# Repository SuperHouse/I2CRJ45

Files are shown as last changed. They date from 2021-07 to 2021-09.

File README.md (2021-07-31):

I2C to RJ45 Breakouts for Light Switch Controller
=================================================

Copyright 2019-2021 SuperHouse Automation Pty Ltd  www.superhouse.tv

These I2C to RJ45 breakouts are one component of the SuperHouse home
automation light switch controller project. They allow light switches
to be connected to a controller such as an Arduino, Raspberry Pi,
or ESP8266/ESP32 board.

The RJ45 sockets on the breakout are connected to I/O channels via
I2C addressable I/O buffers. Each RJ45 socket provides connections for
GND, 12V, and 4 signal lines.

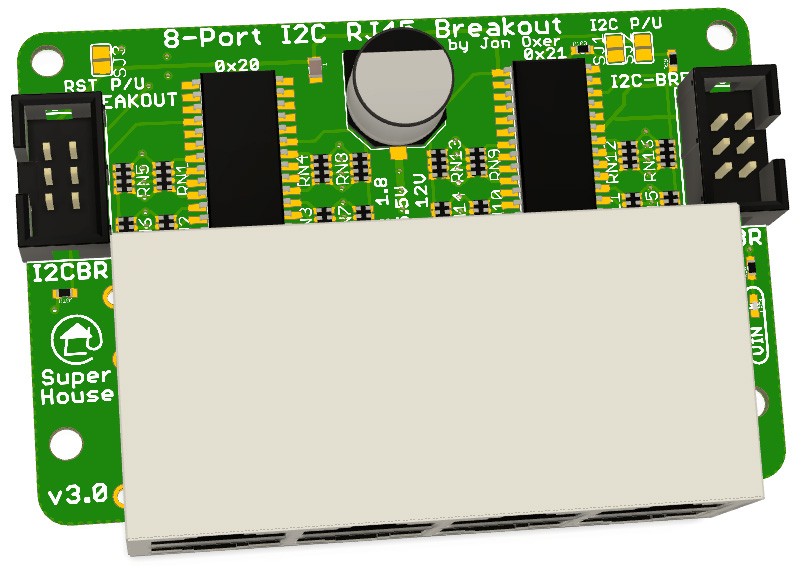
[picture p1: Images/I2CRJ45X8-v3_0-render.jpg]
8-port I2C RJ45 Breakout PCB


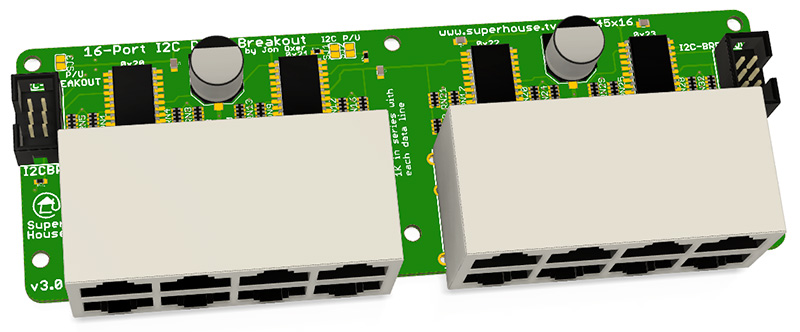
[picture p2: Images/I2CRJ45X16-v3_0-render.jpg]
16-port I2C RJ45 Breakout PCB


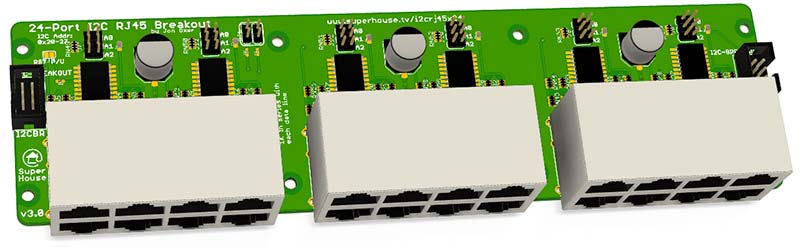
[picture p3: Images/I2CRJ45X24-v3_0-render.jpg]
24-port I2C RJ45 Breakout PCB


Features:

 * RJ45 sockets for connection to light switches over Cat-5
 * I2C interface with interrupt output

More information on the Light Switch Controller project:

  http://www.superhouse.tv/lsc

The LSC also has its own GitHub repo which includes example firmware:

  https://github.com/SuperHouse/LSC

Purchase these breakouts pre-assembled:

  http://www.superhouse.tv/i2crj45

INSTALLATION
------------
The design is saved as an EAGLE project. EAGLE PCB design software is
available from www.cadsoftusa.com free for non-commercial use. To use
this project download it and place the directory containing these files
into the "eagle" directory on your computer. Then open EAGLE and
navigate to the project.

CREDITS
-------
Designed by Jonathan Oxer jon@oxer.com.au

Mechanical drawings by Aaron Knox

DISTRIBUTION
------------
The specific terms of distribution of this project are governed by the
license referenced below.

LICENSE
-------
Licensed under the TAPR Open Hardware License (www.tapr.org/OHL).
The "license" folder within this repository also contains a copy of
this license in plain text format.

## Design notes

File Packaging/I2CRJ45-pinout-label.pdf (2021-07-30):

# I2C Breakout to RJ45

# www.superhouse.tv/i2crj45

A2 A2 A2 A2 A2 A2
A1 A1 A1 A1 A1 A1
A0 A0 A0 A0 A0 A0

A2 A2 A2 A2 A2 A2
A1 A1 A1 A1 A1 A1
A0 A0 A0 A0 A0 A0

# www.superhouse.tv

# I2C Breakout to RJ45

# www.superhouse.tv/i2crj45

A2 A2 A2 A2 A2 A2
A1 A1 A1 A1 A1 A1
A0 A0 A0 A0 A0 A0

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

# www.superhouse.tv

# I2C Breakout to RJ45

# www.superhouse.tv/i2crj45

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

# www.superhouse.tv

# I2C Breakout to RJ45

# www.superhouse.tv/i2crj45

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

# www.superhouse.tv

# I2C Breakout to RJ45

# www.superhouse.tv/i2crj45

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

# www.superhouse.tv

# I2C Breakout to RJ45

# www.superhouse.tv/i2crj45

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

# www.superhouse.tv

# I2C Breakout to RJ45

# www.superhouse.tv/i2crj45

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

# www.superhouse.tv

# I2C Breakout to RJ45

# www.superhouse.tv/i2crj45

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

# www.superhouse.tv

# I2C Breakout to RJ45

# www.superhouse.tv/i2crj45

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

# www.superhouse.tv

# I2C Breakout to RJ45

# www.superhouse.tv/i2crj45

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

# www.superhouse.tv

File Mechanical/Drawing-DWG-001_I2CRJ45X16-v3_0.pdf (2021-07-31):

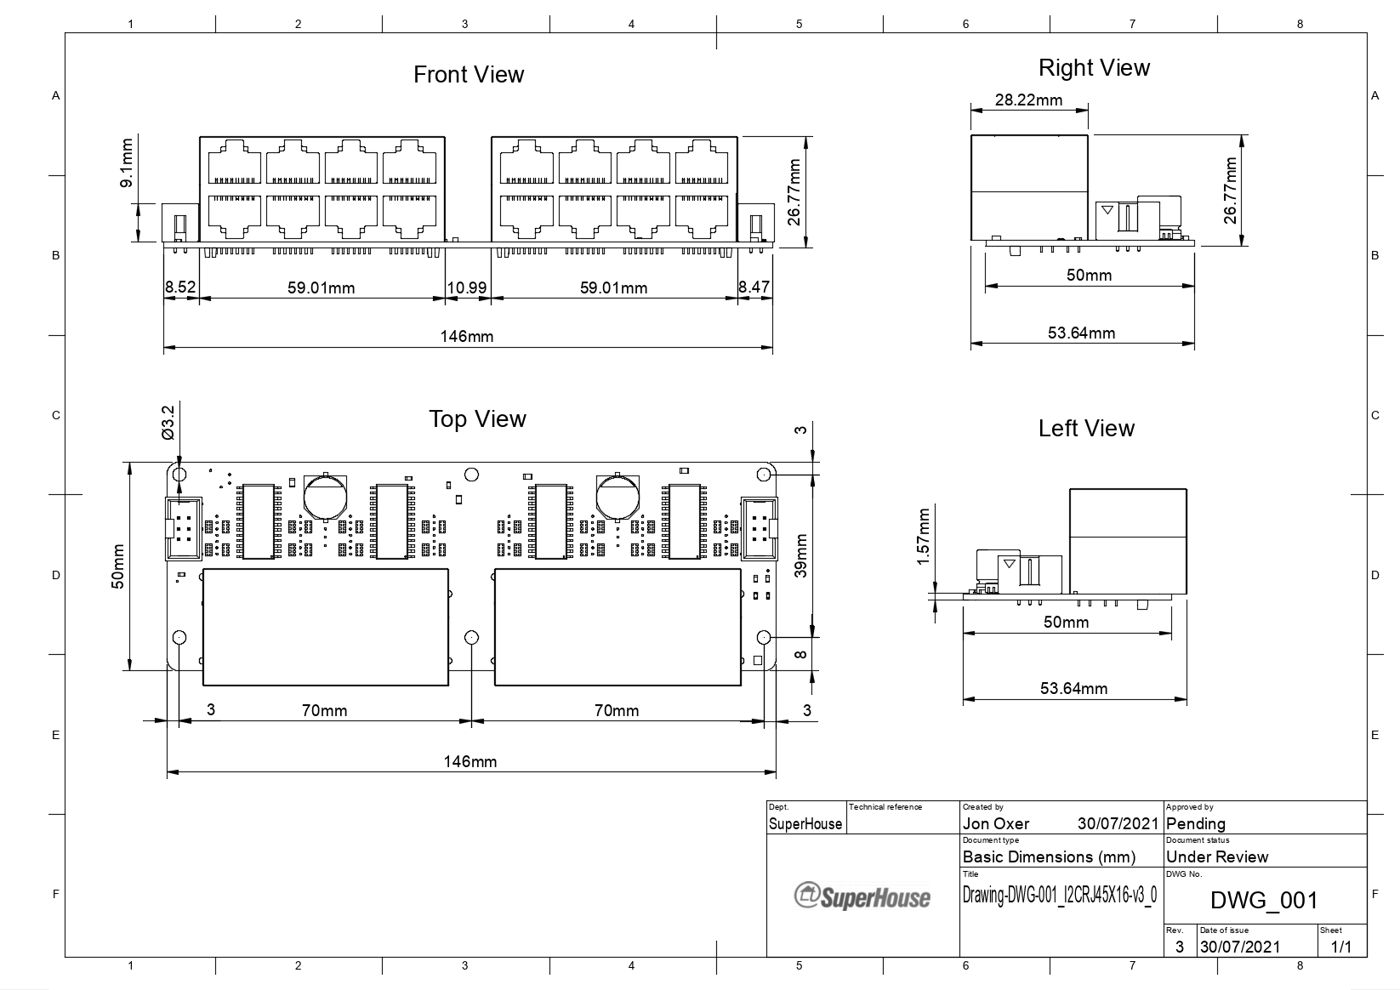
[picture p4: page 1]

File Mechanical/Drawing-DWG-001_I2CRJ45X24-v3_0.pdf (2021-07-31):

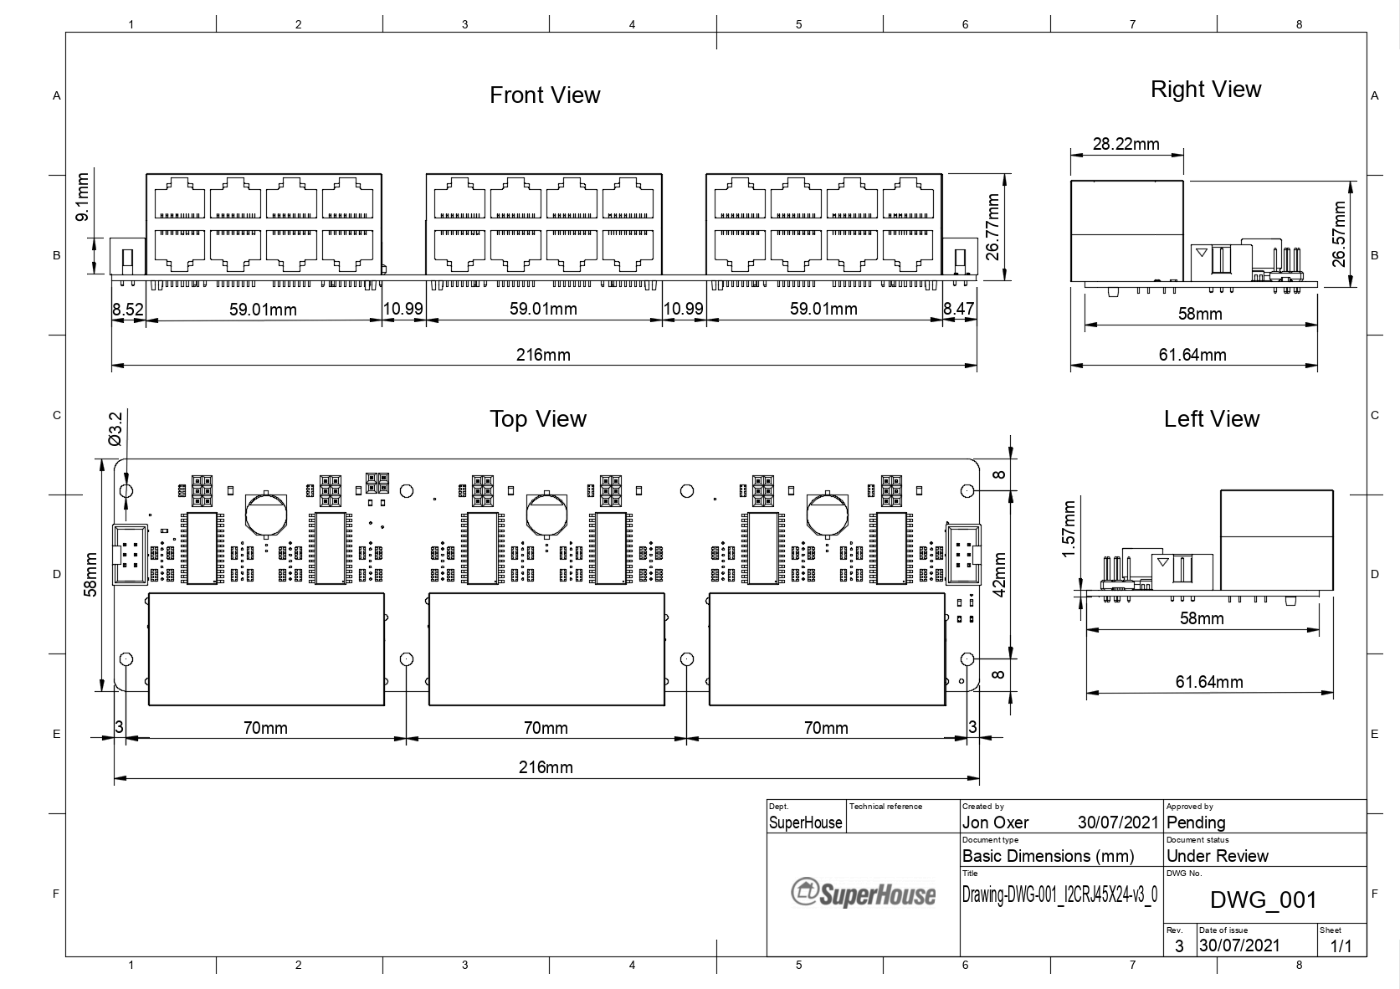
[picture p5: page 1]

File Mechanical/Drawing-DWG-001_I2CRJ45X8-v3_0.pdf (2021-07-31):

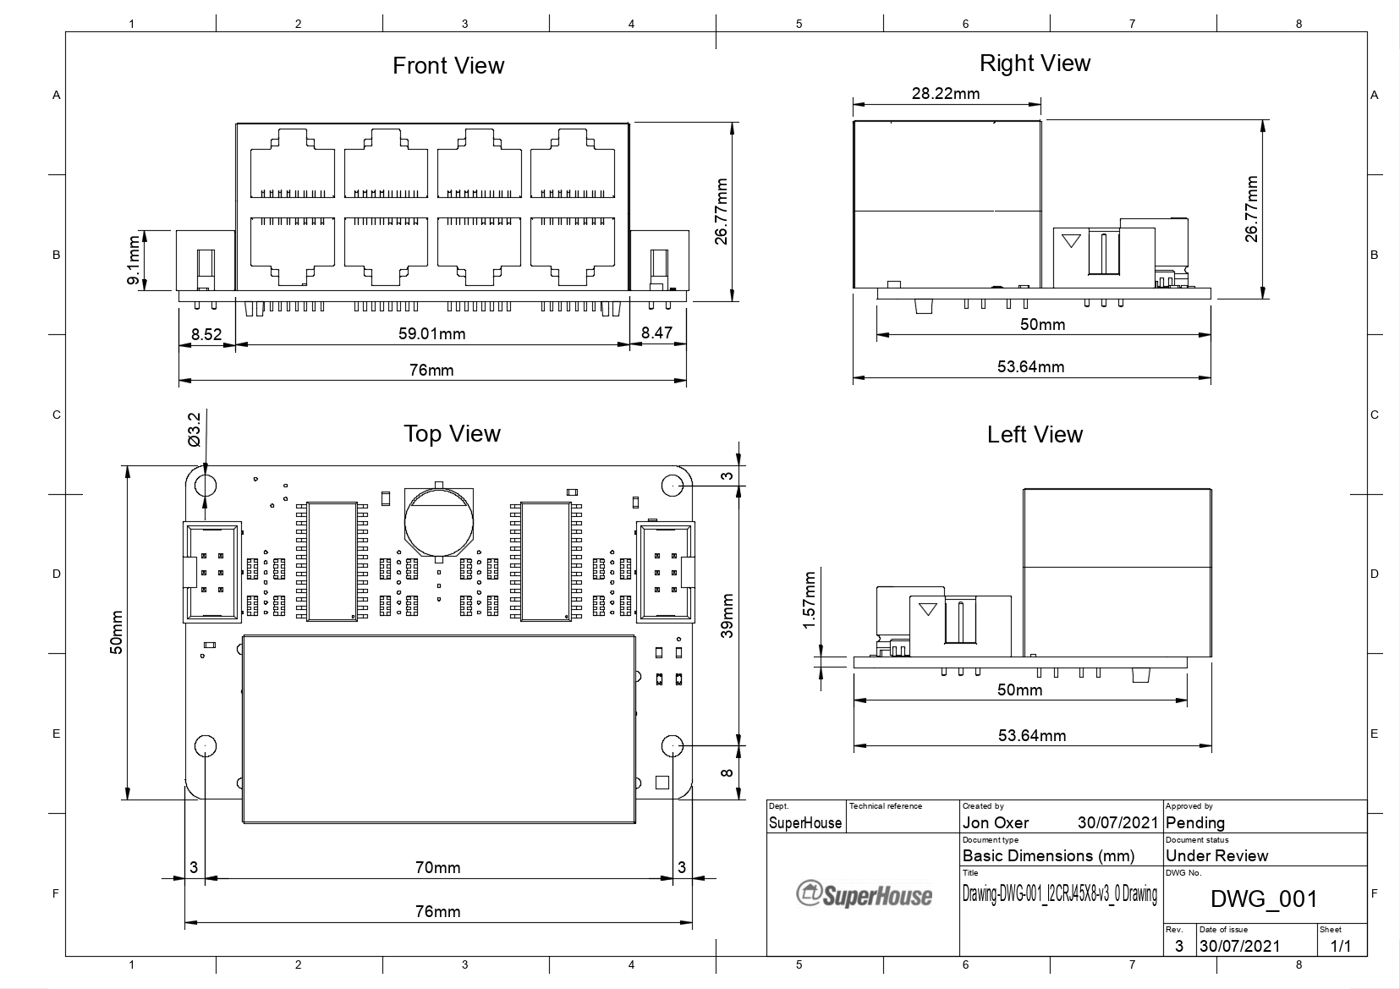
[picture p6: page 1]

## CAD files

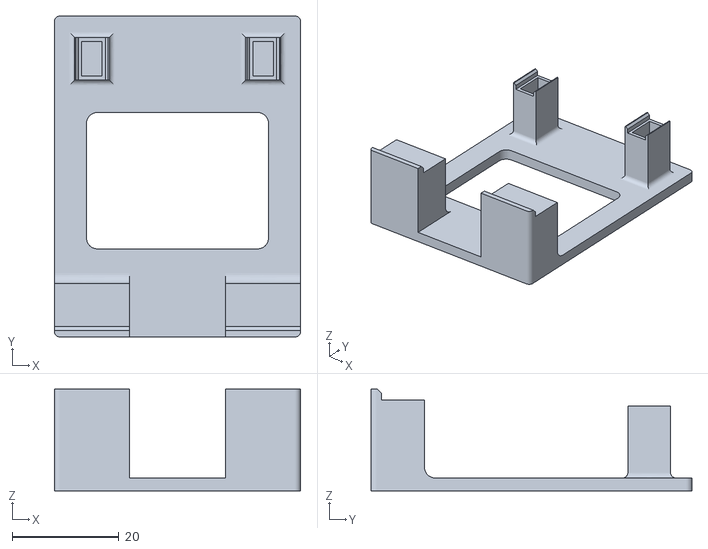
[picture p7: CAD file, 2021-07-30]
Mechanical/Header-Assembly-Jig.stl
46.0 x 60.0 x 19.0

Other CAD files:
Mechanical/Header-Assembly-Jig.f3d
Mechanical/I2CRJ45X16-v3_0.f3d
Mechanical/I2CRJ45X24-v3_0.f3d
Mechanical/I2CRJ45X8-v3_0.f3d

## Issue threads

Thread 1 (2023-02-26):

where to buy 32port version?

kuradi, 2023-02-26:
hello,
have been trying to email, asking question in youtube but i still dont have answer where can i buy 32 port version? it will be on stock at all? when?

gunnar

austinscreations, 2023-03-01:
jon's been busy building the new lab and working on larger client work.

it'll likely take time before more are available.

if / when they are they are available here. https://www.superhouse.tv/product/i2c-rj45-light-switch-breakout/

kuradi, 2023-03-03:
thank you @austinscreations , finally some answer. (y)
maybe you can answer... those 16 ports... are those possible to extend, i mean can i tie 2 of them to behave as 32 ports?

austinscreations, 2023-03-03:
Yes, you can tie two 16 port together. But you should know that two 16 ports will sit in a longer tpace than a 32 port. So you wouldn't be easily able to swap them around later.

If you look at the mechanical pdfs you'll see what I mean about sizing and spacing.

jonoxer, 2023-03-03:
Thanks Austin for following this up. I appreciate it!

I know that stock of the I2C breakouts has been a problem for a long time. After being prompted by this request (and previous requests on the livestreams and in Discord) I pulled out the box of parts and PCBs for them today and found the stencil for the 32-port version after moving it to the factory.

I showed my son the boards and explained what needs to be done to populate them. He's assembled probably nearly 1000 boards for me over the last couple of years and he's really good at it, so I'm going to have him work through the different sizes and assemble enough to get them all into healthy stock levels. I have 100 of the MCP23017 ready to go, which is enough to populate a few.

As Austin said, new stock will show up on the SuperHouse site.

kuradi, 2023-03-05:
thank you, wonderful news! thank you!
as i am totally newbie of superhouse boards and switches... is it possible integrate Light Switch RJ45 Breakout (4-Button) (https://www.superhouse.tv/product/light-switch-rj45-breakout-4-button/) with shelly wall switches (https://www.shelly.cloud/en-ee/products/product-overview/shelly-wall-switch-4-white/shelly-wall-switch-4-black)?

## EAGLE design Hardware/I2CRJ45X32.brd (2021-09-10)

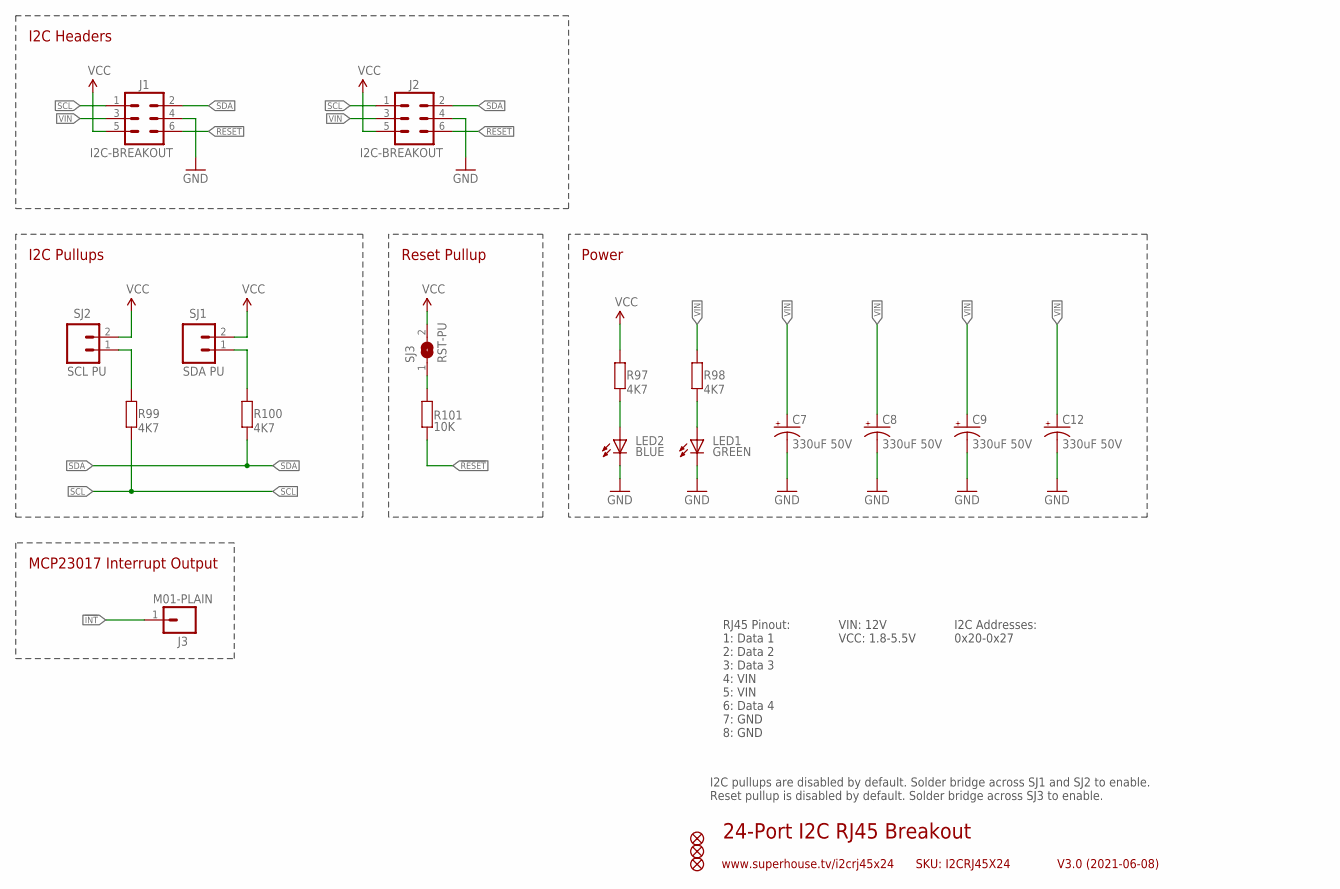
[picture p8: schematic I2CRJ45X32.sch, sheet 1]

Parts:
C7, C8, C9, C12: 330uF 50V; PANASONIC_G
FID1, FID2, FID3: FIDUCIAL1X2.5; FIDUCIAL-1X2.5
J1, J2: I2C-BREAKOUT; 2X3-2.54-SHROUDED
J3: M01-PLAIN; 1X01
LED1: GREEN; LED-0603
LED2: BLUE; LED-0603
R97, R98, R99, R100: 4K7; R0603
R101: 10K; R0603
SJ1: SDA PU; 1X02-P
SJ2: SCL PU; 1X02-P
SJ3: RST-PU; SJ

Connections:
!INT: J3.1; also elsewhere on the board
!RESET: J1.6, J2.6, R101.1; also elsewhere on the board
GND: C7.-, C8.-, C9.-, C12.-, J1.4, J2.4, LED1.C, LED2.C; also elsewhere on the board
unnamed: R99.2, SJ2.1
unnamed: R100.2, SJ1.1
unnamed: R101.2, SJ3.1
unnamed: LED2.A, R97.1
unnamed: LED1.A, R98.1
SCL: J1.1, J2.1, R99.1; also elsewhere on the board
SDA: J1.2, J2.2, R100.1; also elsewhere on the board
VCC: J1.5, J2.5, R97.2, SJ1.2, SJ2.2, SJ3.2; also elsewhere on the board
VIN: C7.+, C8.+, C9.+, C12.+, J1.3, J2.3, R98.2; also elsewhere on the board

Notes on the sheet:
24-Port I2C RJ45 Breakout
V3.0 (2021-06-08)
www.superhouse.tv/i2crj45x24
SKU: I2CRJ45X24
RJ45 Pinout: 1: Data 1 2: Data 2 3: Data 3 4: VIN 5: VIN 6: Data 4 7: GND 8: GND
VIN: 12V VCC: 1.8-5.5V
I2C Addresses: 0x20-0x27
I2C Headers
MCP23017 Interrupt Output
I2C Pullups
I2C pullups are disabled by default. Solder bridge across SJ1 and SJ2 to enable. Reset pullup is disabled by default. Solder bridge across SJ3 to enable.
Power
Reset Pullup

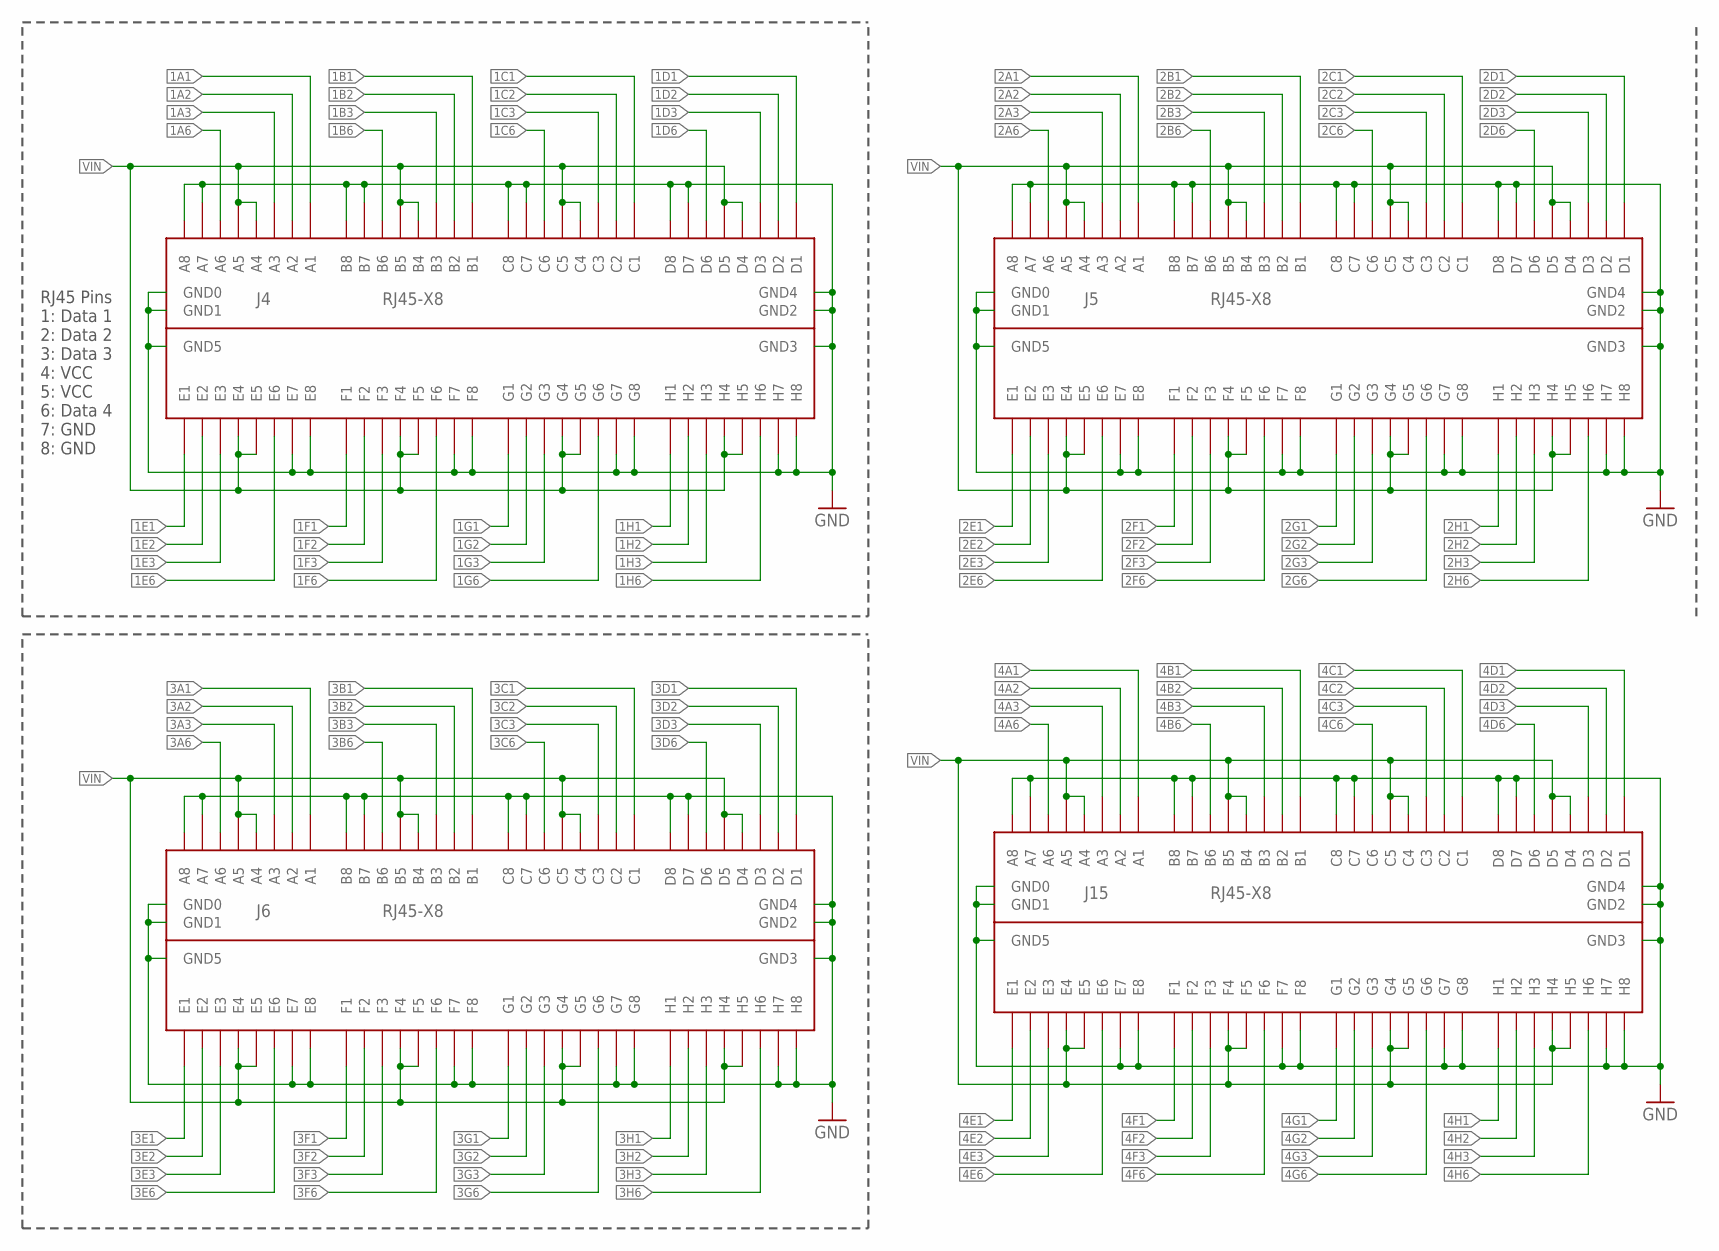
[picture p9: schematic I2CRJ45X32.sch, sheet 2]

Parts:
J4, J5, J6, J15: RJ45-X8; RJ45-2X4

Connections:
1A1: J4.A1; also elsewhere on the board
1A2: J4.A2; also elsewhere on the board
1A3: J4.A3; also elsewhere on the board
1A6: J4.A6; also elsewhere on the board
1B1: J4.B1; also elsewhere on the board
1B2: J4.B2; also elsewhere on the board
1B3: J4.B3; also elsewhere on the board
1B6: J4.B6; also elsewhere on the board
1C1: J4.C1; also elsewhere on the board
1C2: J4.C2; also elsewhere on the board
1C3: J4.C3; also elsewhere on the board
1C6: J4.C6; also elsewhere on the board
1D1: J4.D1; also elsewhere on the board
1D2: J4.D2; also elsewhere on the board
1D3: J4.D3; also elsewhere on the board
1D6: J4.D6; also elsewhere on the board
1E1: J4.E1; also elsewhere on the board
1E2: J4.E2; also elsewhere on the board
1E3: J4.E3; also elsewhere on the board
1E6: J4.E6; also elsewhere on the board
1F1: J4.F1; also elsewhere on the board
1F2: J4.F2; also elsewhere on the board
1F3: J4.F3; also elsewhere on the board
1F6: J4.F6; also elsewhere on the board
1G1: J4.G1; also elsewhere on the board
1G2: J4.G2; also elsewhere on the board
1G3: J4.G3; also elsewhere on the board
1G6: J4.G6; also elsewhere on the board
1H1: J4.H1; also elsewhere on the board
1H2: J4.H2; also elsewhere on the board
1H3: J4.H3; also elsewhere on the board
1H6: J4.H6; also elsewhere on the board
2A1: J5.A1; also elsewhere on the board
2A2: J5.A2; also elsewhere on the board
2A3: J5.A3; also elsewhere on the board
2A6: J5.A6; also elsewhere on the board
2B1: J5.B1; also elsewhere on the board
2B2: J5.B2; also elsewhere on the board
2B3: J5.B3; also elsewhere on the board
2B6: J5.B6; also elsewhere on the board
2C1: J5.C1; also elsewhere on the board
2C2: J5.C2; also elsewhere on the board
2C3: J5.C3; also elsewhere on the board
2C6: J5.C6; also elsewhere on the board
2D1: J5.D1; also elsewhere on the board
2D2: J5.D2; also elsewhere on the board
2D3: J5.D3; also elsewhere on the board
2D6: J5.D6; also elsewhere on the board
2E1: J5.E1; also elsewhere on the board
2E2: J5.E2; also elsewhere on the board
2E3: J5.E3; also elsewhere on the board
2E6: J5.E6; also elsewhere on the board
2F1: J5.F1; also elsewhere on the board
2F2: J5.F2; also elsewhere on the board
2F3: J5.F3; also elsewhere on the board
2F6: J5.F6; also elsewhere on the board
2G1: J5.G1; also elsewhere on the board
2G2: J5.G2; also elsewhere on the board
2G3: J5.G3; also elsewhere on the board
2G6: J5.G6; also elsewhere on the board
2H1: J5.H1; also elsewhere on the board
2H2: J5.H2; also elsewhere on the board
2H3: J5.H3; also elsewhere on the board
2H6: J5.H6; also elsewhere on the board
3A1: J6.A1; also elsewhere on the board
3A2: J6.A2; also elsewhere on the board
3A3: J6.A3; also elsewhere on the board
3A6: J6.A6; also elsewhere on the board
3B1: J6.B1; also elsewhere on the board
3B2: J6.B2; also elsewhere on the board
3B3: J6.B3; also elsewhere on the board
3B6: J6.B6; also elsewhere on the board
3C1: J6.C1; also elsewhere on the board
3C2: J6.C2; also elsewhere on the board
3C3: J6.C3; also elsewhere on the board
3C6: J6.C6; also elsewhere on the board
3D1: J6.D1; also elsewhere on the board
3D2: J6.D2; also elsewhere on the board
3D3: J6.D3; also elsewhere on the board
3D6: J6.D6; also elsewhere on the board
3E1: J6.E1; also elsewhere on the board
3E2: J6.E2; also elsewhere on the board
3E3: J6.E3; also elsewhere on the board
3E6: J6.E6; also elsewhere on the board
3F1: J6.F1; also elsewhere on the board
3F2: J6.F2; also elsewhere on the board
3F3: J6.F3; also elsewhere on the board
3F6: J6.F6; also elsewhere on the board
3G1: J6.G1; also elsewhere on the board
3G2: J6.G2; also elsewhere on the board
3G3: J6.G3; also elsewhere on the board
3G6: J6.G6; also elsewhere on the board
3H1: J6.H1; also elsewhere on the board
3H2: J6.H2; also elsewhere on the board
3H3: J6.H3; also elsewhere on the board
3H6: J6.H6; also elsewhere on the board
4A1: J15.A1; also elsewhere on the board
4A2: J15.A2; also elsewhere on the board
4A3: J15.A3; also elsewhere on the board
4A6: J15.A6; also elsewhere on the board
4B1: J15.B1; also elsewhere on the board
4B2: J15.B2; also elsewhere on the board
4B3: J15.B3; also elsewhere on the board
4B6: J15.B6; also elsewhere on the board
4C1: J15.C1; also elsewhere on the board
4C2: J15.C2; also elsewhere on the board
4C3: J15.C3; also elsewhere on the board
4C6: J15.C6; also elsewhere on the board
4D1: J15.D1; also elsewhere on the board
4D2: J15.D2; also elsewhere on the board
4D3: J15.D3; also elsewhere on the board
4D6: J15.D6; also elsewhere on the board
4E1: J15.E1; also elsewhere on the board
4E2: J15.E2; also elsewhere on the board
4E3: J15.E3; also elsewhere on the board
4E6: J15.E6; also elsewhere on the board
4F1: J15.F1; also elsewhere on the board
4F2: J15.F2; also elsewhere on the board
4F3: J15.F3; also elsewhere on the board
4F6: J15.F6; also elsewhere on the board
4G1: J15.G1; also elsewhere on the board
4G2: J15.G2; also elsewhere on the board
4G3: J15.G3; also elsewhere on the board
4G6: J15.G6; also elsewhere on the board
4H1: J15.H1; also elsewhere on the board
4H2: J15.H2; also elsewhere on the board
4H3: J15.H3; also elsewhere on the board
4H6: J15.H6; also elsewhere on the board
GND: J4.A7, J4.A8, J4.B7, J4.B8, J4.C7, J4.C8, J4.D7, J4.D8, J4.E7, J4.E8, J4.F7, J4.F8, J4.G7, J4.G8, J4.GND0, J4.GND1, J4.GND2, J4.GND3, J4.GND4, J4.GND5, J4.H7, J4.H8, J5.A7, J5.A8, J5.B7, J5.B8, J5.C7, J5.C8, J5.D7, J5.D8, J5.E7, J5.E8, J5.F7, J5.F8, J5.G7, J5.G8, J5.GND0, J5.GND1, J5.GND2, J5.GND3, J5.GND4, J5.GND5, J5.H7, J5.H8, J6.A7, J6.A8, J6.B7, J6.B8, J6.C7, J6.C8, J6.D7, J6.D8, J6.E7, J6.E8, J6.F7, J6.F8, J6.G7, J6.G8, J6.GND0, J6.GND1, J6.GND2, J6.GND3, J6.GND4, J6.GND5, J6.H7, J6.H8, J15.A7, J15.A8, J15.B7, J15.B8, J15.C7, J15.C8, J15.D7, J15.D8, J15.E7, J15.E8, J15.F7, J15.F8, J15.G7, J15.G8, J15.GND0, J15.GND1, J15.GND2, J15.GND3, J15.GND4, J15.GND5, J15.H7, J15.H8; also elsewhere on the board
VIN: J4.A4, J4.A5, J4.B4, J4.B5, J4.C4, J4.C5, J4.D4, J4.D5, J4.E4, J4.E5, J4.F4, J4.F5, J4.G4, J4.G5, J4.H4, J4.H5, J5.A4, J5.A5, J5.B4, J5.B5, J5.C4, J5.C5, J5.D4, J5.D5, J5.E4, J5.E5, J5.F4, J5.F5, J5.G4, J5.G5, J5.H4, J5.H5, J6.A4, J6.A5, J6.B4, J6.B5, J6.C4, J6.C5, J6.D4, J6.D5, J6.E4, J6.E5, J6.F4, J6.F5, J6.G4, J6.G5, J6.H4, J6.H5, J15.A4, J15.A5, J15.B4, J15.B5, J15.C4, J15.C5, J15.D4, J15.D5, J15.E4, J15.E5, J15.F4, J15.F5, J15.G4, J15.G5, J15.H4, J15.H5; also elsewhere on the board

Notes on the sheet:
RJ45 Pins 1: Data 1 2: Data 2 3: Data 3 4: VCC 5: VCC 6: Data 4 7: GND 8: GND

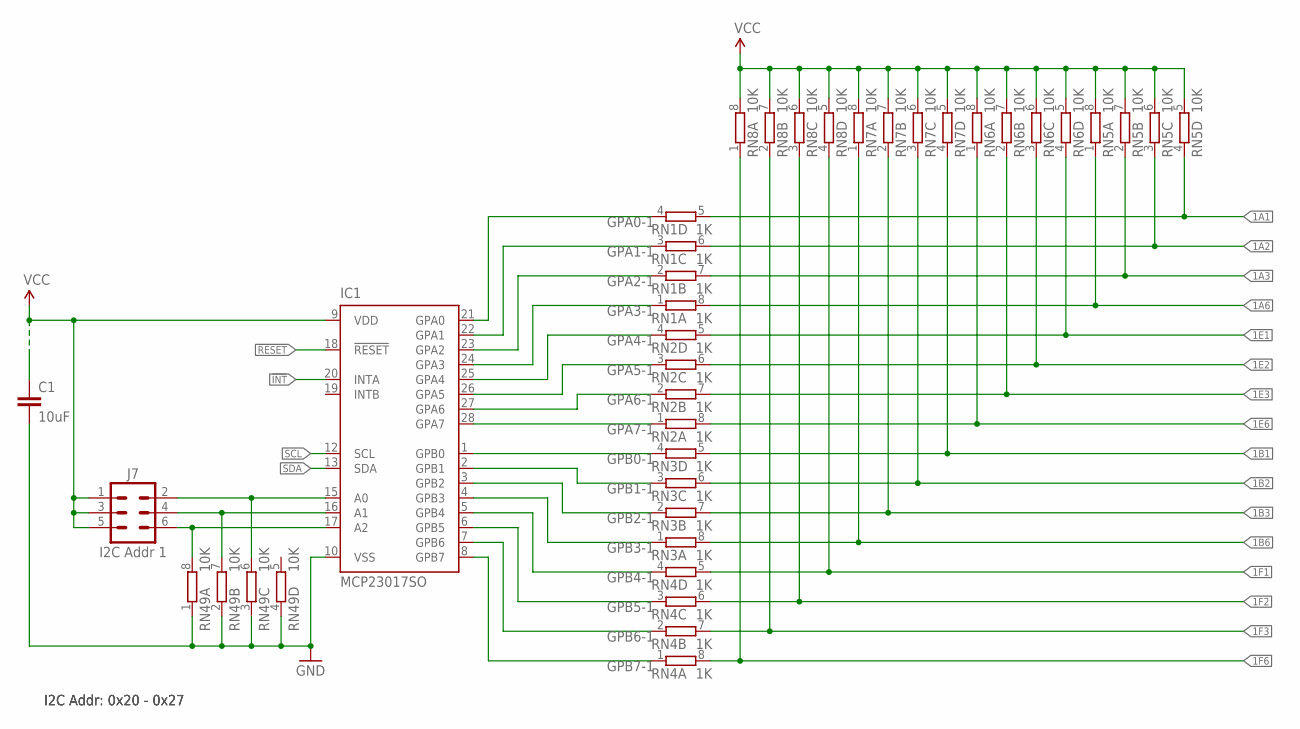
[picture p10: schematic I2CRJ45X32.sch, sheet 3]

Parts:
C1: 10uF; C0805
IC1: MCP23017SO; SO28W
J7: I2C Addr 1; 2X03-P
RN1, RN2, RN3, RN4: 1K; CAY16
RN5, RN6, RN7, RN8, RN49: 10K; CAY16

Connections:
1A1: RN1.5 (2), RN5.4 (1); also elsewhere on the board
1A2: RN1.6 (2), RN5.3 (1); also elsewhere on the board
1A3: RN1.7 (2), RN5.2 (1); also elsewhere on the board
1A6: RN1.8 (2), RN5.1; also elsewhere on the board
1B1: RN3.5 (2), RN7.4 (1); also elsewhere on the board
1B2: RN3.6 (2), RN7.3 (1); also elsewhere on the board
1B3: RN3.7 (2), RN7.2 (1); also elsewhere on the board
1B6: RN3.8 (2), RN7.1; also elsewhere on the board
1E1: RN2.5 (2), RN6.4 (1); also elsewhere on the board
1E2: RN2.6 (2), RN6.3 (1); also elsewhere on the board
1E3: RN2.7 (2), RN6.2 (1); also elsewhere on the board
1E6: RN2.8 (2), RN6.1; also elsewhere on the board
1F1: RN4.5 (2), RN8.4 (1); also elsewhere on the board
1F2: RN4.6 (2), RN8.3 (1); also elsewhere on the board
1F3: RN4.7 (2), RN8.2 (1); also elsewhere on the board
1F6: RN4.8 (2), RN8.1; also elsewhere on the board
!INT: IC1.20 (INTA); also elsewhere on the board
!RESET: IC1.18 (!RESET); also elsewhere on the board
GND: C1.2, IC1.10 (VSS), RN49.1, RN49.2 (1), RN49.3 (1), RN49.4 (1); also elsewhere on the board
GPA0-1: IC1.21 (GPA0), RN1.4 (1)
GPA1-1: IC1.22 (GPA1), RN1.3 (1)
GPA2-1: IC1.23 (GPA2), RN1.2 (1)
GPA3-1: IC1.24 (GPA3), RN1.1
GPA4-1: IC1.25 (GPA4), RN2.4 (1)
GPA5-1: IC1.26 (GPA5), RN2.3 (1)
GPA6-1: IC1.27 (GPA6), RN2.2 (1)
GPA7-1: IC1.28 (GPA7), RN2.1
GPB0-1: IC1.1 (GPB0), RN3.4 (1)
GPB1-1: IC1.2 (GPB1), RN3.3 (1)
GPB2-1: IC1.3 (GPB2), RN3.2 (1)
GPB3-1: IC1.4 (GPB3), RN3.1
GPB4-1: IC1.5 (GPB4), RN4.4 (1)
GPB5-1: IC1.6 (GPB5), RN4.3 (1)
GPB6-1: IC1.7 (GPB6), RN4.2 (1)
GPB7-1: IC1.8 (GPB7), RN4.1
unnamed: IC1.17 (A2), J7.6, RN49.8 (2)
unnamed: IC1.16 (A1), J7.4, RN49.7 (2)
unnamed: IC1.15 (A0), J7.2, RN49.6 (2)
SCL: IC1.12 (SCL); also elsewhere on the board
SDA: IC1.13 (SDA); also elsewhere on the board
VCC: C1.1, IC1.9 (VDD), J7.1, J7.3, J7.5, RN5.5 (2), RN5.6 (2), RN5.7 (2), RN5.8 (2), RN6.5 (2), RN6.6 (2), RN6.7 (2), RN6.8 (2), RN7.5 (2), RN7.6 (2), RN7.7 (2), RN7.8 (2), RN8.5 (2), RN8.6 (2), RN8.7 (2), RN8.8 (2); also elsewhere on the board

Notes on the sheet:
I2C Addr: 0x20 - 0x27

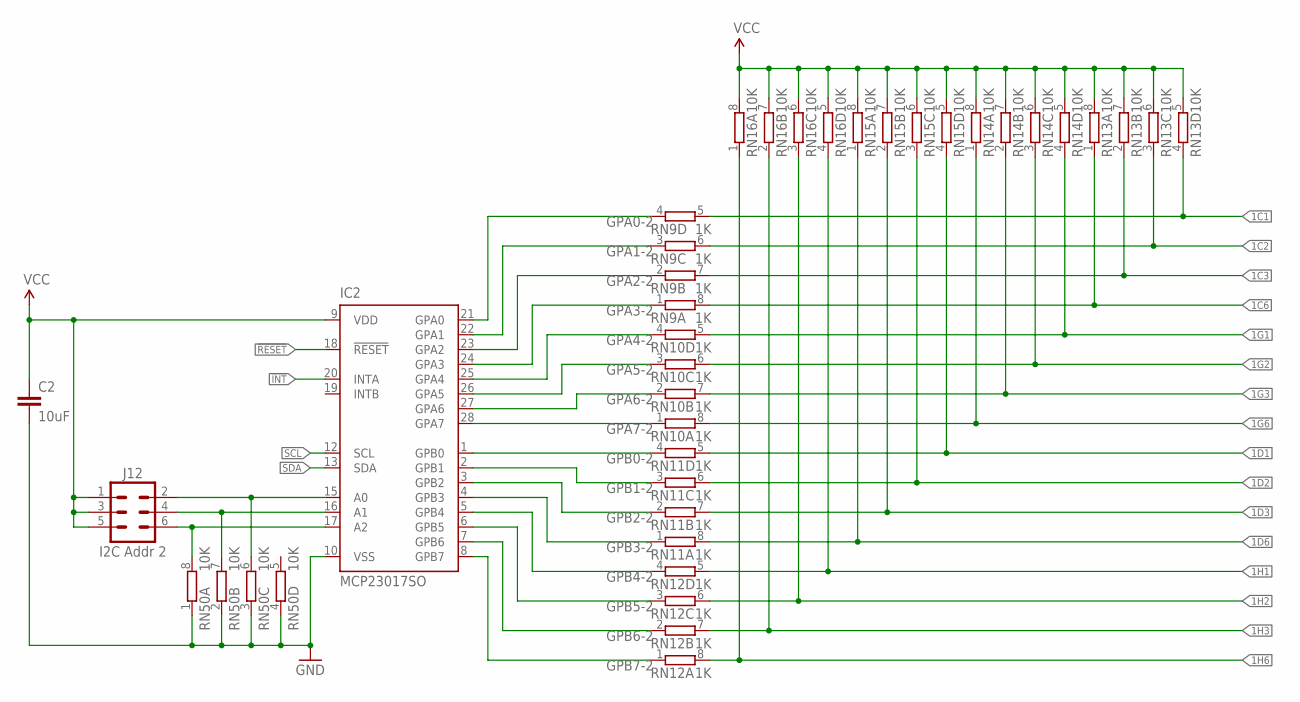
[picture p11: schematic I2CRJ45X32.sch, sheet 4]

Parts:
C2: 10uF; C0805
IC2: MCP23017SO; SO28W
J12: I2C Addr 2; 2X03-P
RN9, RN10, RN11, RN12: 1K; CAY16
RN13, RN14, RN15, RN16, RN50: 10K; CAY16

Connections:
1C1: RN9.5 (2), RN13.4 (1); also elsewhere on the board
1C2: RN9.6 (2), RN13.3 (1); also elsewhere on the board
1C3: RN9.7 (2), RN13.2 (1); also elsewhere on the board
1C6: RN9.8 (2), RN13.1; also elsewhere on the board
1D1: RN11.5 (2), RN15.4 (1); also elsewhere on the board
1D2: RN11.6 (2), RN15.3 (1); also elsewhere on the board
1D3: RN11.7 (2), RN15.2 (1); also elsewhere on the board
1D6: RN11.8 (2), RN15.1; also elsewhere on the board
1G1: RN10.5 (2), RN14.4 (1); also elsewhere on the board
1G2: RN10.6 (2), RN14.3 (1); also elsewhere on the board
1G3: RN10.7 (2), RN14.2 (1); also elsewhere on the board
1G6: RN10.8 (2), RN14.1; also elsewhere on the board
1H1: RN12.5 (2), RN16.4 (1); also elsewhere on the board
1H2: RN12.6 (2), RN16.3 (1); also elsewhere on the board
1H3: RN12.7 (2), RN16.2 (1); also elsewhere on the board
1H6: RN12.8 (2), RN16.1; also elsewhere on the board
!INT: IC2.20 (INTA); also elsewhere on the board
!RESET: IC2.18 (!RESET); also elsewhere on the board
GND: C2.2, IC2.10 (VSS), RN50.1, RN50.2 (1), RN50.3 (1), RN50.4 (1); also elsewhere on the board
GPA0-2: IC2.21 (GPA0), RN9.4 (1)
GPA1-2: IC2.22 (GPA1), RN9.3 (1)
GPA2-2: IC2.23 (GPA2), RN9.2 (1)
GPA3-2: IC2.24 (GPA3), RN9.1
GPA4-2: IC2.25 (GPA4), RN10.4 (1)
GPA5-2: IC2.26 (GPA5), RN10.3 (1)
GPA6-2: IC2.27 (GPA6), RN10.2 (1)
GPA7-2: IC2.28 (GPA7), RN10.1
GPB0-2: IC2.1 (GPB0), RN11.4 (1)
GPB1-2: IC2.2 (GPB1), RN11.3 (1)
GPB2-2: IC2.3 (GPB2), RN11.2 (1)
GPB3-2: IC2.4 (GPB3), RN11.1
GPB4-2: IC2.5 (GPB4), RN12.4 (1)
GPB5-2: IC2.6 (GPB5), RN12.3 (1)
GPB6-2: IC2.7 (GPB6), RN12.2 (1)
GPB7-2: IC2.8 (GPB7), RN12.1
unnamed: IC2.15 (A0), J12.2, RN50.6 (2)
unnamed: IC2.16 (A1), J12.4, RN50.7 (2)
unnamed: IC2.17 (A2), J12.6, RN50.8 (2)
SCL: IC2.12 (SCL); also elsewhere on the board
SDA: IC2.13 (SDA); also elsewhere on the board
VCC: C2.1, IC2.9 (VDD), J12.1, J12.3, J12.5, RN13.5 (2), RN13.6 (2), RN13.7 (2), RN13.8 (2), RN14.5 (2), RN14.6 (2), RN14.7 (2), RN14.8 (2), RN15.5 (2), RN15.6 (2), RN15.7 (2), RN15.8 (2), RN16.5 (2), RN16.6 (2), RN16.7 (2), RN16.8 (2); also elsewhere on the board

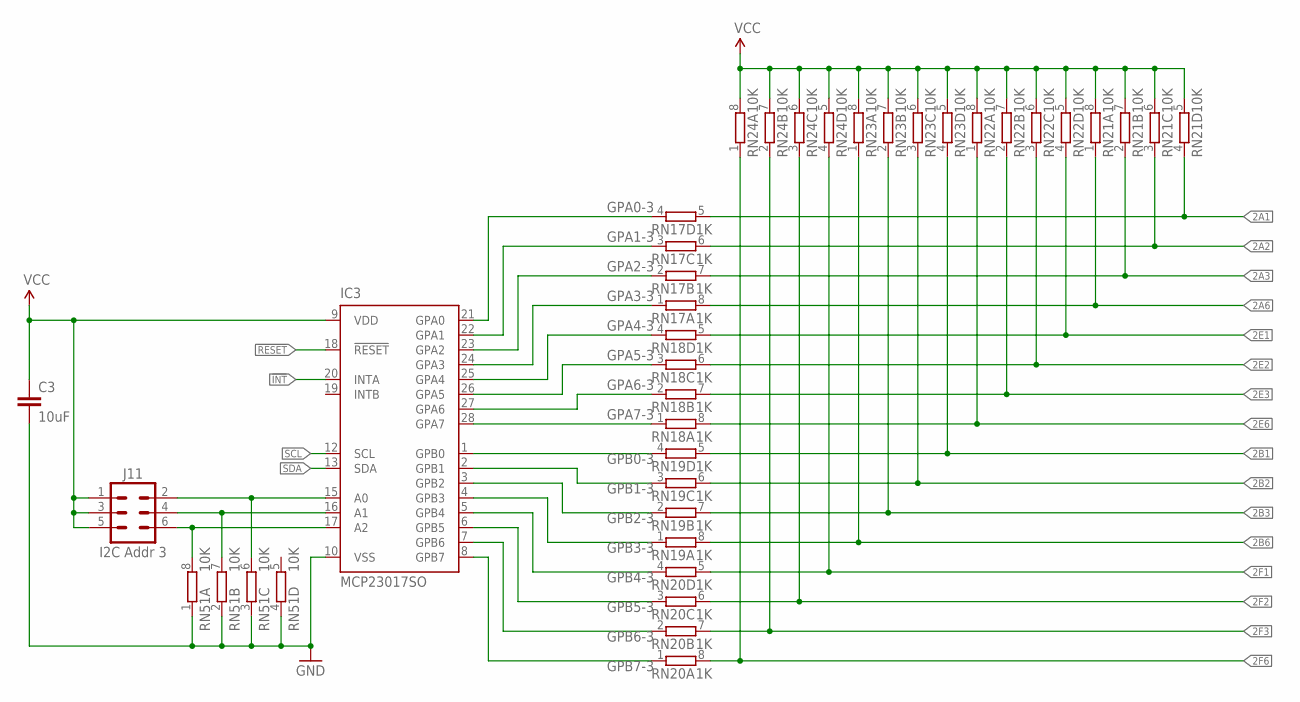
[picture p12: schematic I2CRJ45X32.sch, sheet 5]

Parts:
C3: 10uF; C0805
IC3: MCP23017SO; SO28W
J11: I2C Addr 3; 2X03-P
RN17, RN18, RN19, RN20: 1K; CAY16
RN21, RN22, RN23, RN24, RN51: 10K; CAY16

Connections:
2A1: RN17.5 (2), RN21.4 (1); also elsewhere on the board
2A2: RN17.6 (2), RN21.3 (1); also elsewhere on the board
2A3: RN17.7 (2), RN21.2 (1); also elsewhere on the board
2A6: RN17.8 (2), RN21.1; also elsewhere on the board
2B1: RN19.5 (2), RN23.4 (1); also elsewhere on the board
2B2: RN19.6 (2), RN23.3 (1); also elsewhere on the board
2B3: RN19.7 (2), RN23.2 (1); also elsewhere on the board
2B6: RN19.8 (2), RN23.1; also elsewhere on the board
2E1: RN18.5 (2), RN22.4 (1); also elsewhere on the board
2E2: RN18.6 (2), RN22.3 (1); also elsewhere on the board
2E3: RN18.7 (2), RN22.2 (1); also elsewhere on the board
2E6: RN18.8 (2), RN22.1; also elsewhere on the board
2F1: RN20.5 (2), RN24.4 (1); also elsewhere on the board
2F2: RN20.6 (2), RN24.3 (1); also elsewhere on the board
2F3: RN20.7 (2), RN24.2 (1); also elsewhere on the board
2F6: RN20.8 (2), RN24.1; also elsewhere on the board
!INT: IC3.20 (INTA); also elsewhere on the board
!RESET: IC3.18 (!RESET); also elsewhere on the board
GND: C3.2, IC3.10 (VSS), RN51.1, RN51.2 (1), RN51.3 (1), RN51.4 (1); also elsewhere on the board
GPA0-3: IC3.21 (GPA0), RN17.4 (1)
GPA1-3: IC3.22 (GPA1), RN17.3 (1)
GPA2-3: IC3.23 (GPA2), RN17.2 (1)
GPA3-3: IC3.24 (GPA3), RN17.1
GPA4-3: IC3.25 (GPA4), RN18.4 (1)
GPA5-3: IC3.26 (GPA5), RN18.3 (1)
GPA6-3: IC3.27 (GPA6), RN18.2 (1)
GPA7-3: IC3.28 (GPA7), RN18.1
GPB0-3: IC3.1 (GPB0), RN19.4 (1)
GPB1-3: IC3.2 (GPB1), RN19.3 (1)
GPB2-3: IC3.3 (GPB2), RN19.2 (1)
GPB3-3: IC3.4 (GPB3), RN19.1
GPB4-3: IC3.5 (GPB4), RN20.4 (1)
GPB5-3: IC3.6 (GPB5), RN20.3 (1)
GPB6-3: IC3.7 (GPB6), RN20.2 (1)
GPB7-3: IC3.8 (GPB7), RN20.1
unnamed: IC3.17 (A2), J11.6, RN51.8 (2)
unnamed: IC3.15 (A0), J11.2, RN51.6 (2)
unnamed: IC3.16 (A1), J11.4, RN51.7 (2)
SCL: IC3.12 (SCL); also elsewhere on the board
SDA: IC3.13 (SDA); also elsewhere on the board
VCC: C3.1, IC3.9 (VDD), J11.1, J11.3, J11.5, RN21.5 (2), RN21.6 (2), RN21.7 (2), RN21.8 (2), RN22.5 (2), RN22.6 (2), RN22.7 (2), RN22.8 (2), RN23.5 (2), RN23.6 (2), RN23.7 (2), RN23.8 (2), RN24.5 (2), RN24.6 (2), RN24.7 (2), RN24.8 (2); also elsewhere on the board

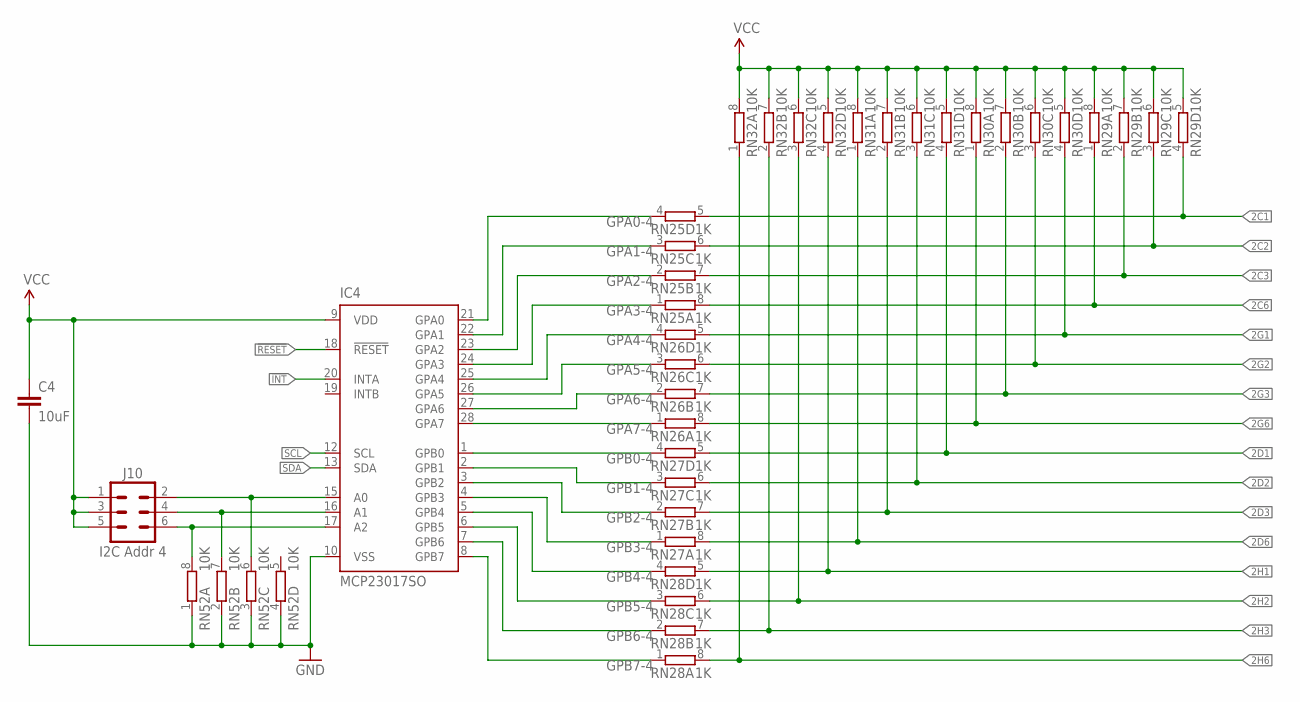
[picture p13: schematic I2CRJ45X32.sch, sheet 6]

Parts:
C4: 10uF; C0805
IC4: MCP23017SO; SO28W
J10: I2C Addr 4; 2X03-P
RN25, RN26, RN27, RN28: 1K; CAY16
RN29, RN30, RN31, RN32, RN52: 10K; CAY16

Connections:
2C1: RN25.5 (2), RN29.4 (1); also elsewhere on the board
2C2: RN25.6 (2), RN29.3 (1); also elsewhere on the board
2C3: RN25.7 (2), RN29.2 (1); also elsewhere on the board
2C6: RN25.8 (2), RN29.1; also elsewhere on the board
2D1: RN27.5 (2), RN31.4 (1); also elsewhere on the board
2D2: RN27.6 (2), RN31.3 (1); also elsewhere on the board
2D3: RN27.7 (2), RN31.2 (1); also elsewhere on the board
2D6: RN27.8 (2), RN31.1; also elsewhere on the board
2G1: RN26.5 (2), RN30.4 (1); also elsewhere on the board
2G2: RN26.6 (2), RN30.3 (1); also elsewhere on the board
2G3: RN26.7 (2), RN30.2 (1); also elsewhere on the board
2G6: RN26.8 (2), RN30.1; also elsewhere on the board
2H1: RN28.5 (2), RN32.4 (1); also elsewhere on the board
2H2: RN28.6 (2), RN32.3 (1); also elsewhere on the board
2H3: RN28.7 (2), RN32.2 (1); also elsewhere on the board
2H6: RN28.8 (2), RN32.1; also elsewhere on the board
!INT: IC4.20 (INTA); also elsewhere on the board
!RESET: IC4.18 (!RESET); also elsewhere on the board
GND: C4.2, IC4.10 (VSS), RN52.1, RN52.2 (1), RN52.3 (1), RN52.4 (1); also elsewhere on the board
GPA0-4: IC4.21 (GPA0), RN25.4 (1)
GPA1-4: IC4.22 (GPA1), RN25.3 (1)
GPA2-4: IC4.23 (GPA2), RN25.2 (1)
GPA3-4: IC4.24 (GPA3), RN25.1
GPA4-4: IC4.25 (GPA4), RN26.4 (1)
GPA5-4: IC4.26 (GPA5), RN26.3 (1)
GPA6-4: IC4.27 (GPA6), RN26.2 (1)
GPA7-4: IC4.28 (GPA7), RN26.1
GPB0-4: IC4.1 (GPB0), RN27.4 (1)
GPB1-4: IC4.2 (GPB1), RN27.3 (1)
GPB2-4: IC4.3 (GPB2), RN27.2 (1)
GPB3-4: IC4.4 (GPB3), RN27.1
GPB4-4: IC4.5 (GPB4), RN28.4 (1)
GPB5-4: IC4.6 (GPB5), RN28.3 (1)
GPB6-4: IC4.7 (GPB6), RN28.2 (1)
GPB7-4: IC4.8 (GPB7), RN28.1
unnamed: IC4.17 (A2), J10.6, RN52.8 (2)
unnamed: IC4.15 (A0), J10.2, RN52.6 (2)
unnamed: IC4.16 (A1), J10.4, RN52.7 (2)
SCL: IC4.12 (SCL); also elsewhere on the board
SDA: IC4.13 (SDA); also elsewhere on the board
VCC: C4.1, IC4.9 (VDD), J10.1, J10.3, J10.5, RN29.5 (2), RN29.6 (2), RN29.7 (2), RN29.8 (2), RN30.5 (2), RN30.6 (2), RN30.7 (2), RN30.8 (2), RN31.5 (2), RN31.6 (2), RN31.7 (2), RN31.8 (2), RN32.5 (2), RN32.6 (2), RN32.7 (2), RN32.8 (2); also elsewhere on the board

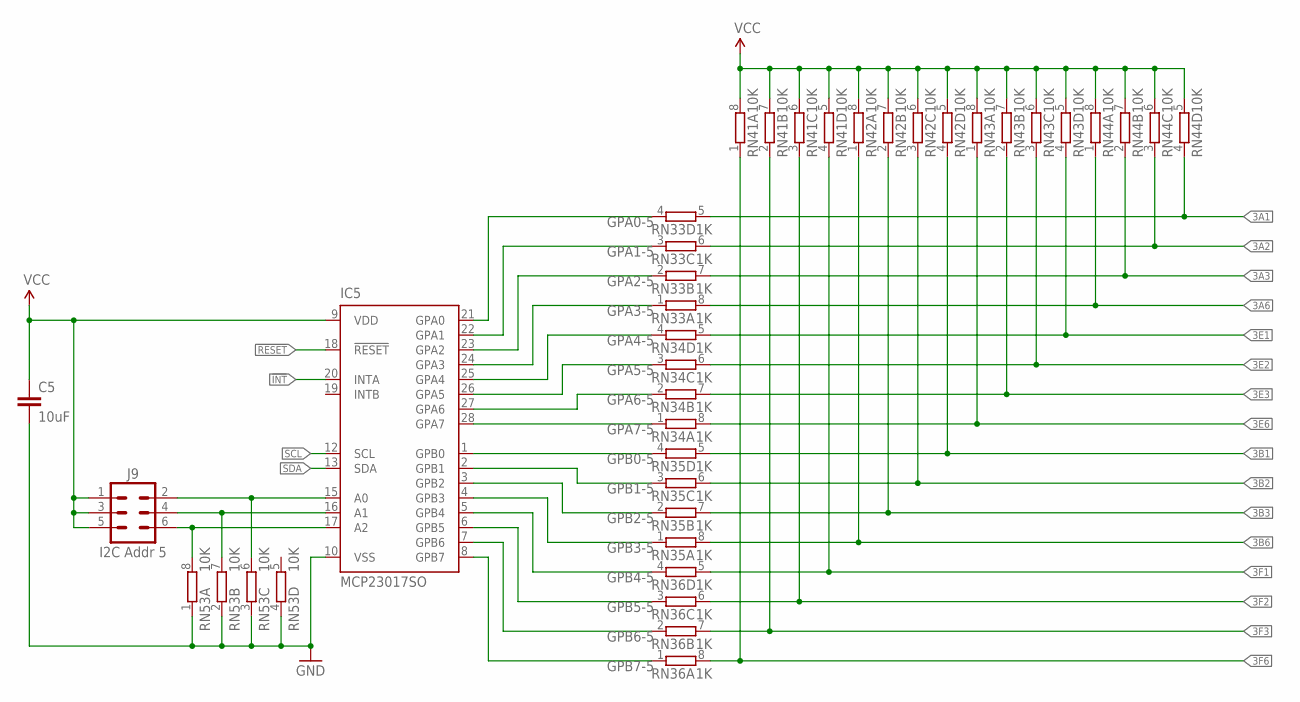
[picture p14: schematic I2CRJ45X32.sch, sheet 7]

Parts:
C5: 10uF; C0805
IC5: MCP23017SO; SO28W
J9: I2C Addr 5; 2X03-P
RN33, RN34, RN35, RN36: 1K; CAY16
RN41, RN42, RN43, RN44, RN53: 10K; CAY16

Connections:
3A1: RN33.5 (2), RN44.4 (1); also elsewhere on the board
3A2: RN33.6 (2), RN44.3 (1); also elsewhere on the board
3A3: RN33.7 (2), RN44.2 (1); also elsewhere on the board
3A6: RN33.8 (2), RN44.1; also elsewhere on the board
3B1: RN35.5 (2), RN42.4 (1); also elsewhere on the board
3B2: RN35.6 (2), RN42.3 (1); also elsewhere on the board
3B3: RN35.7 (2), RN42.2 (1); also elsewhere on the board
3B6: RN35.8 (2), RN42.1; also elsewhere on the board
3E1: RN34.5 (2), RN43.4 (1); also elsewhere on the board
3E2: RN34.6 (2), RN43.3 (1); also elsewhere on the board
3E3: RN34.7 (2), RN43.2 (1); also elsewhere on the board
3E6: RN34.8 (2), RN43.1; also elsewhere on the board
3F1: RN36.5 (2), RN41.4 (1); also elsewhere on the board
3F2: RN36.6 (2), RN41.3 (1); also elsewhere on the board
3F3: RN36.7 (2), RN41.2 (1); also elsewhere on the board
3F6: RN36.8 (2), RN41.1; also elsewhere on the board
!INT: IC5.20 (INTA); also elsewhere on the board
!RESET: IC5.18 (!RESET); also elsewhere on the board
GND: C5.2, IC5.10 (VSS), RN53.1, RN53.2 (1), RN53.3 (1), RN53.4 (1); also elsewhere on the board
GPA0-5: IC5.21 (GPA0), RN33.4 (1)
GPA1-5: IC5.22 (GPA1), RN33.3 (1)
GPA2-5: IC5.23 (GPA2), RN33.2 (1)
GPA3-5: IC5.24 (GPA3), RN33.1
GPA4-5: IC5.25 (GPA4), RN34.4 (1)
GPA5-5: IC5.26 (GPA5), RN34.3 (1)
GPA6-5: IC5.27 (GPA6), RN34.2 (1)
GPA7-5: IC5.28 (GPA7), RN34.1
GPB0-5: IC5.1 (GPB0), RN35.4 (1)
GPB1-5: IC5.2 (GPB1), RN35.3 (1)
GPB2-5: IC5.3 (GPB2), RN35.2 (1)
GPB3-5: IC5.4 (GPB3), RN35.1
GPB4-5: IC5.5 (GPB4), RN36.4 (1)
GPB5-5: IC5.6 (GPB5), RN36.3 (1)
GPB6-5: IC5.7 (GPB6), RN36.2 (1)
GPB7-5: IC5.8 (GPB7), RN36.1
unnamed: IC5.17 (A2), J9.6, RN53.8 (2)
unnamed: IC5.15 (A0), J9.2, RN53.6 (2)
unnamed: IC5.16 (A1), J9.4, RN53.7 (2)
SCL: IC5.12 (SCL); also elsewhere on the board
SDA: IC5.13 (SDA); also elsewhere on the board
VCC: C5.1, IC5.9 (VDD), J9.1, J9.3, J9.5, RN41.5 (2), RN41.6 (2), RN41.7 (2), RN41.8 (2), RN42.5 (2), RN42.6 (2), RN42.7 (2), RN42.8 (2), RN43.5 (2), RN43.6 (2), RN43.7 (2), RN43.8 (2), RN44.5 (2), RN44.6 (2), RN44.7 (2), RN44.8 (2); also elsewhere on the board

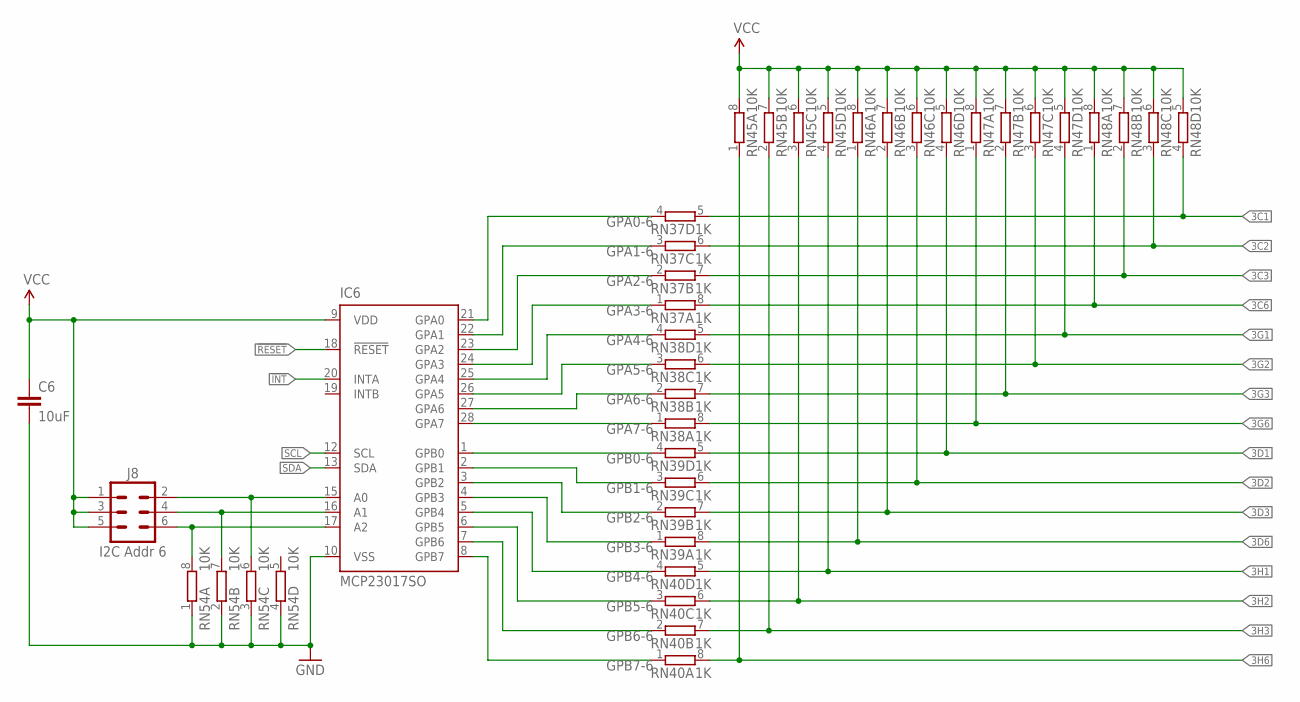
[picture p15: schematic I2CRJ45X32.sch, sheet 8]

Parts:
C6: 10uF; C0805
IC6: MCP23017SO; SO28W
J8: I2C Addr 6; 2X03-P
RN37, RN38, RN39, RN40: 1K; CAY16
RN45, RN46, RN47, RN48, RN54: 10K; CAY16

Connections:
3C1: RN37.5 (2), RN48.4 (1); also elsewhere on the board
3C2: RN37.6 (2), RN48.3 (1); also elsewhere on the board
3C3: RN37.7 (2), RN48.2 (1); also elsewhere on the board
3C6: RN37.8 (2), RN48.1; also elsewhere on the board
3D1: RN39.5 (2), RN46.4 (1); also elsewhere on the board
3D2: RN39.6 (2), RN46.3 (1); also elsewhere on the board
3D3: RN39.7 (2), RN46.2 (1); also elsewhere on the board
3D6: RN39.8 (2), RN46.1; also elsewhere on the board
3G1: RN38.5 (2), RN47.4 (1); also elsewhere on the board
3G2: RN38.6 (2), RN47.3 (1); also elsewhere on the board
3G3: RN38.7 (2), RN47.2 (1); also elsewhere on the board
3G6: RN38.8 (2), RN47.1; also elsewhere on the board
3H1: RN40.5 (2), RN45.4 (1); also elsewhere on the board
3H2: RN40.6 (2), RN45.3 (1); also elsewhere on the board
3H3: RN40.7 (2), RN45.2 (1); also elsewhere on the board
3H6: RN40.8 (2), RN45.1; also elsewhere on the board
!INT: IC6.20 (INTA); also elsewhere on the board
!RESET: IC6.18 (!RESET); also elsewhere on the board
GND: C6.2, IC6.10 (VSS), RN54.1, RN54.2 (1), RN54.3 (1), RN54.4 (1); also elsewhere on the board
GPA0-6: IC6.21 (GPA0), RN37.4 (1)
GPA1-6: IC6.22 (GPA1), RN37.3 (1)
GPA2-6: IC6.23 (GPA2), RN37.2 (1)
GPA3-6: IC6.24 (GPA3), RN37.1
GPA4-6: IC6.25 (GPA4), RN38.4 (1)
GPA5-6: IC6.26 (GPA5), RN38.3 (1)
GPA6-6: IC6.27 (GPA6), RN38.2 (1)
GPA7-6: IC6.28 (GPA7), RN38.1
GPB0-6: IC6.1 (GPB0), RN39.4 (1)
GPB1-6: IC6.2 (GPB1), RN39.3 (1)
GPB2-6: IC6.3 (GPB2), RN39.2 (1)
GPB3-6: IC6.4 (GPB3), RN39.1
GPB4-6: IC6.5 (GPB4), RN40.4 (1)
GPB5-6: IC6.6 (GPB5), RN40.3 (1)
GPB6-6: IC6.7 (GPB6), RN40.2 (1)
GPB7-6: IC6.8 (GPB7), RN40.1
unnamed: IC6.17 (A2), J8.6, RN54.8 (2)
unnamed: IC6.15 (A0), J8.2, RN54.6 (2)
unnamed: IC6.16 (A1), J8.4, RN54.7 (2)
SCL: IC6.12 (SCL); also elsewhere on the board
SDA: IC6.13 (SDA); also elsewhere on the board
VCC: C6.1, IC6.9 (VDD), J8.1, J8.3, J8.5, RN45.5 (2), RN45.6 (2), RN45.7 (2), RN45.8 (2), RN46.5 (2), RN46.6 (2), RN46.7 (2), RN46.8 (2), RN47.5 (2), RN47.6 (2), RN47.7 (2), RN47.8 (2), RN48.5 (2), RN48.6 (2), RN48.7 (2), RN48.8 (2); also elsewhere on the board

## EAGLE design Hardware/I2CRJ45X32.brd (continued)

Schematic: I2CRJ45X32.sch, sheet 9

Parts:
C10: 10uF; C0805
IC7: MCP23017SO; SO28W
J13: I2C Addr 6; 2X03-P
RN55, RN56, RN57, RN58: 1K; CAY16
RN59, RN60, RN61, RN62, RN63: 10K; CAY16

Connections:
4A1: RN55.5 (2), RN62.4 (1); also elsewhere on the board
4A2: RN55.6 (2), RN62.3 (1); also elsewhere on the board
4A3: RN55.7 (2), RN62.2 (1); also elsewhere on the board
4A6: RN55.8 (2), RN62.1; also elsewhere on the board
4B1: RN57.5 (2), RN60.4 (1); also elsewhere on the board
4B2: RN57.6 (2), RN60.3 (1); also elsewhere on the board
4B3: RN57.7 (2), RN60.2 (1); also elsewhere on the board
4B6: RN57.8 (2), RN60.1; also elsewhere on the board
4E1: RN56.5 (2), RN61.4 (1); also elsewhere on the board
4E2: RN56.6 (2), RN61.3 (1); also elsewhere on the board
4E3: RN56.7 (2), RN61.2 (1); also elsewhere on the board
4E6: RN56.8 (2), RN61.1; also elsewhere on the board
4F1: RN58.5 (2), RN59.4 (1); also elsewhere on the board
4F2: RN58.6 (2), RN59.3 (1); also elsewhere on the board
4F3: RN58.7 (2), RN59.2 (1); also elsewhere on the board
4F6: RN58.8 (2), RN59.1; also elsewhere on the board
!INT: IC7.20 (INTA); also elsewhere on the board
!RESET: IC7.18 (!RESET); also elsewhere on the board
GND: C10.2, IC7.10 (VSS), RN63.1, RN63.2 (1), RN63.3 (1), RN63.4 (1); also elsewhere on the board
GPA0-7: IC7.21 (GPA0), RN55.4 (1)
GPA1-7: IC7.22 (GPA1), RN55.3 (1)
GPA2-7: IC7.23 (GPA2), RN55.2 (1)
GPA3-7: IC7.24 (GPA3), RN55.1
GPA4-7: IC7.25 (GPA4), RN56.4 (1)
GPA5-7: IC7.26 (GPA5), RN56.3 (1)
GPA6-7: IC7.27 (GPA6), RN56.2 (1)
GPA7-7: IC7.28 (GPA7), RN56.1
GPB0-7: IC7.1 (GPB0), RN57.4 (1)
GPB1-7: IC7.2 (GPB1), RN57.3 (1)
GPB2-7: IC7.3 (GPB2), RN57.2 (1)
GPB3-7: IC7.4 (GPB3), RN57.1
GPB4-7: IC7.5 (GPB4), RN58.4 (1)
GPB5-7: IC7.6 (GPB5), RN58.3 (1)
GPB6-7: IC7.7 (GPB6), RN58.2 (1)
GPB7-7: IC7.8 (GPB7), RN58.1
unnamed: IC7.17 (A2), J13.6, RN63.8 (2)
unnamed: IC7.15 (A0), J13.2, RN63.6 (2)
unnamed: IC7.16 (A1), J13.4, RN63.7 (2)
SCL: IC7.12 (SCL); also elsewhere on the board
SDA: IC7.13 (SDA); also elsewhere on the board
VCC: C10.1, IC7.9 (VDD), J13.1, J13.3, J13.5, RN59.5 (2), RN59.6 (2), RN59.7 (2), RN59.8 (2), RN60.5 (2), RN60.6 (2), RN60.7 (2), RN60.8 (2), RN61.5 (2), RN61.6 (2), RN61.7 (2), RN61.8 (2), RN62.5 (2), RN62.6 (2), RN62.7 (2), RN62.8 (2); also elsewhere on the board

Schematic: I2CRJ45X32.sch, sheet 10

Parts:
C11: 10uF; C0805
IC8: MCP23017SO; SO28W
J14: I2C Addr 6; 2X03-P
RN64, RN65, RN66, RN67: 1K; CAY16
RN68, RN69, RN70, RN71, RN72: 10K; CAY16

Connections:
4C1: RN64.5 (2), RN71.4 (1); also elsewhere on the board
4C2: RN64.6 (2), RN71.3 (1); also elsewhere on the board
4C3: RN64.7 (2), RN71.2 (1); also elsewhere on the board
4C6: RN64.8 (2), RN71.1; also elsewhere on the board
4D1: RN66.5 (2), RN69.4 (1); also elsewhere on the board
4D2: RN66.6 (2), RN69.3 (1); also elsewhere on the board
4D3: RN66.7 (2), RN69.2 (1); also elsewhere on the board
4D6: RN66.8 (2), RN69.1; also elsewhere on the board
4G1: RN65.5 (2), RN70.4 (1); also elsewhere on the board
4G2: RN65.6 (2), RN70.3 (1); also elsewhere on the board
4G3: RN65.7 (2), RN70.2 (1); also elsewhere on the board
4G6: RN65.8 (2), RN70.1; also elsewhere on the board
4H1: RN67.5 (2), RN68.4 (1); also elsewhere on the board
4H2: RN67.6 (2), RN68.3 (1); also elsewhere on the board
4H3: RN67.7 (2), RN68.2 (1); also elsewhere on the board
4H6: RN67.8 (2), RN68.1; also elsewhere on the board
!INT: IC8.20 (INTA); also elsewhere on the board
!RESET: IC8.18 (!RESET); also elsewhere on the board
GND: C11.2, IC8.10 (VSS), RN72.1, RN72.2 (1), RN72.3 (1), RN72.4 (1); also elsewhere on the board
GPA0-8: IC8.21 (GPA0), RN64.4 (1)
GPA1-8: IC8.22 (GPA1), RN64.3 (1)
GPA2-8: IC8.23 (GPA2), RN64.2 (1)
GPA3-8: IC8.24 (GPA3), RN64.1
GPA4-8: IC8.25 (GPA4), RN65.4 (1)
GPA5-8: IC8.26 (GPA5), RN65.3 (1)
GPA6-8: IC8.27 (GPA6), RN65.2 (1)
GPA7-8: IC8.28 (GPA7), RN65.1
GPB0-8: IC8.1 (GPB0), RN66.4 (1)
GPB1-8: IC8.2 (GPB1), RN66.3 (1)
GPB2-8: IC8.3 (GPB2), RN66.2 (1)
GPB3-8: IC8.4 (GPB3), RN66.1
GPB4-8: IC8.5 (GPB4), RN67.4 (1)
GPB5-8: IC8.6 (GPB5), RN67.3 (1)
GPB6-8: IC8.7 (GPB6), RN67.2 (1)
GPB7-8: IC8.8 (GPB7), RN67.1
unnamed: IC8.17 (A2), J14.6, RN72.8 (2)
unnamed: IC8.15 (A0), J14.2, RN72.6 (2)
unnamed: IC8.16 (A1), J14.4, RN72.7 (2)
SCL: IC8.12 (SCL); also elsewhere on the board
SDA: IC8.13 (SDA); also elsewhere on the board
VCC: C11.1, IC8.9 (VDD), J14.1, J14.3, J14.5, RN68.5 (2), RN68.6 (2), RN68.7 (2), RN68.8 (2), RN69.5 (2), RN69.6 (2), RN69.7 (2), RN69.8 (2), RN70.5 (2), RN70.6 (2), RN70.7 (2), RN70.8 (2), RN71.5 (2), RN71.6 (2), RN71.7 (2), RN71.8 (2); also elsewhere on the board

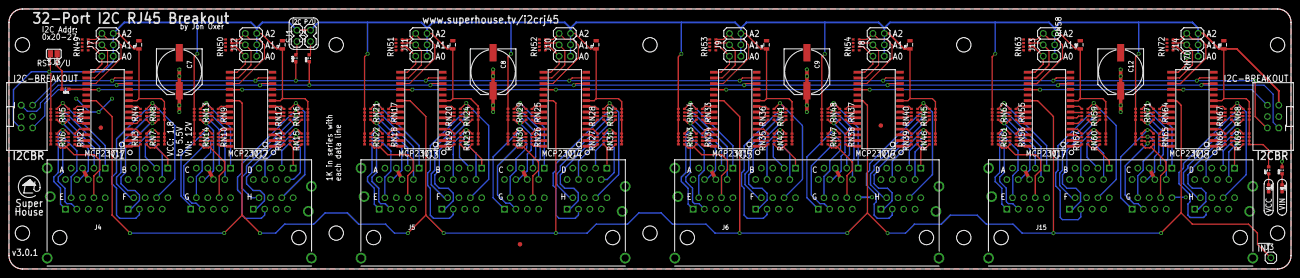
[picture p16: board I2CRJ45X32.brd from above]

Board: 2 copper layers, 286.0 x 58.0 mm, 120 parts (0 on the bottom side), 292 nets.

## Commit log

2021-07-20 Separation of I2C breakouts from main LSC project.
2021-07-30 Added 3D models of all board versions and header assembly jig.
    [Header-Assembly-Jig.f3d, Header-Assembly-Jig.stl, I2CRJ45X16-v3_0.f3d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]
2021-09-05 Added 32-port version.
    [I2CRJ45X32.brd, I2CRJ45X32.sch]
2021-09-10 Final tweaks and DRC for v3.0.1 release.
    [I2CRJ45X32.brd]
